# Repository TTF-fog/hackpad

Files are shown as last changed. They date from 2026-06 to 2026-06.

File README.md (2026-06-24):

# hackpad!!
a simple 9-key macropad with backlighting

# Why
- ...i've never made one before
- i did actually need a macropad
- i wanted to use a ribbon connector but didn't have anything that needed one
- i needed to remember how to CAD

# Sub(Links)
- [Zine.pdf](zine.pdf)
- [Design](design/)
- [BOM](BOM.csv)
- [Gerbers](gerbers.zip) 
- [Schematic PDF](design/hackpad.pdf)

> DO FLASHING BEFORE ASSEMBLY!
# flashing
- make sure you have QMK installed
- copy the firmware/firmware directory into the keyboards directory of your qmk installation
- run qmk compile -kb wackpad -km default
- on the xiao, ground the BOOT pad while plugging it into the computer
- drop the resultant .uf2 from the previous previous (englishj) step into the flash drive
- after the copying is done (may take a while), the drive will automatically eject
# hardware assembly
- solder the components
- print the case
- place the pcb in the case so the mounting holes go through the stands
- align the OLED ribbon to go through the display hole
- assembly done!

# images
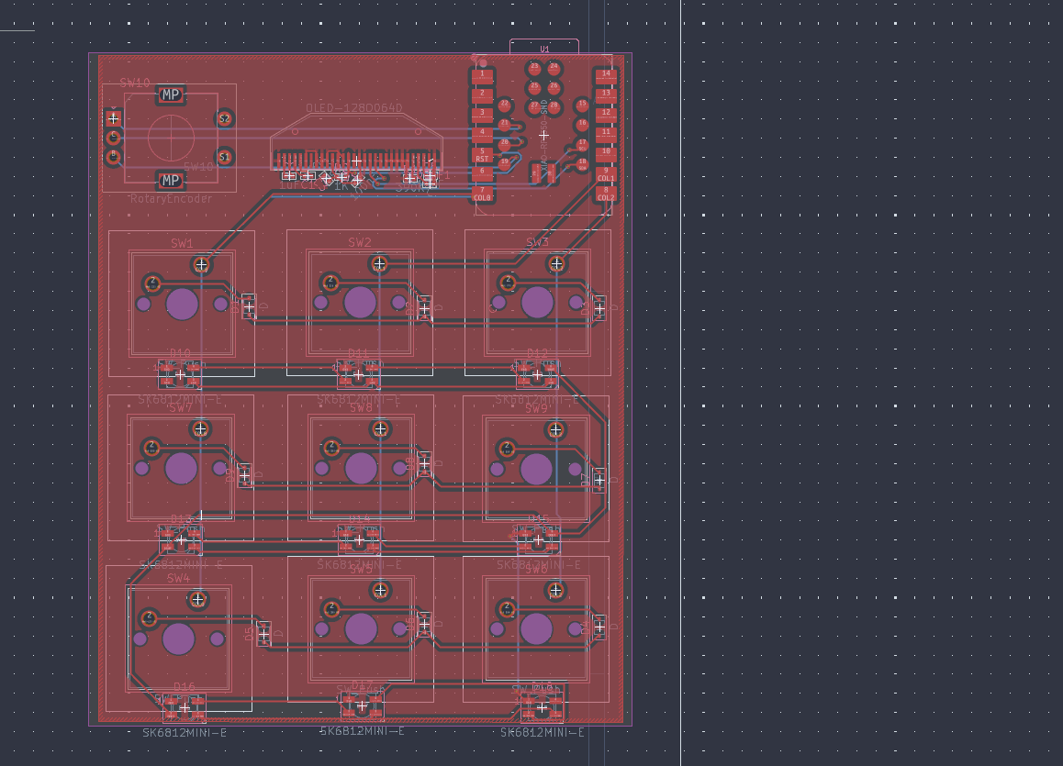
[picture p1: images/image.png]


> PCB

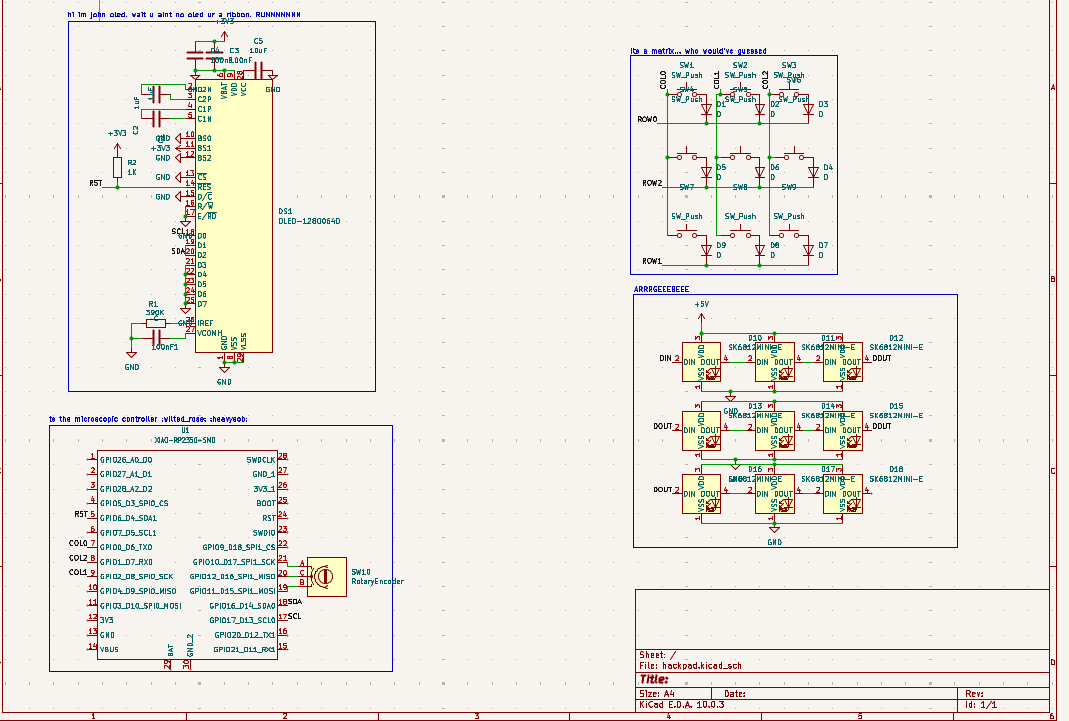
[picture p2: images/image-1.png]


>Schematic

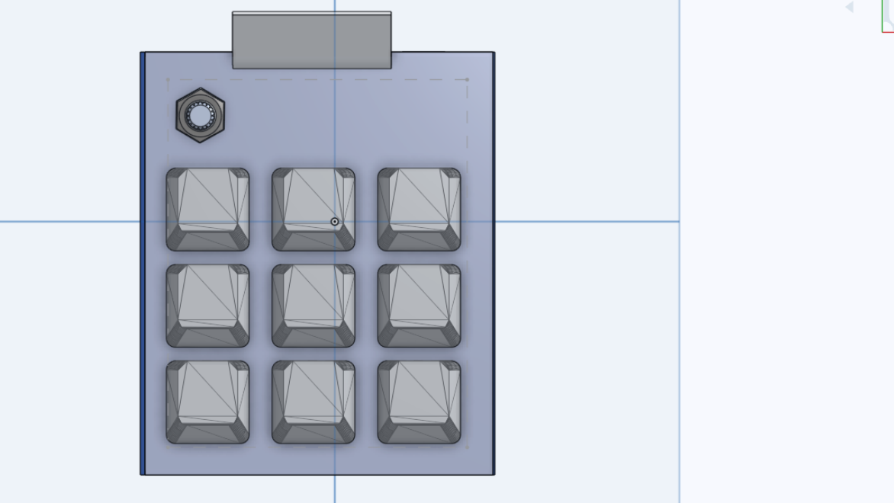
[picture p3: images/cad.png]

> the CAD

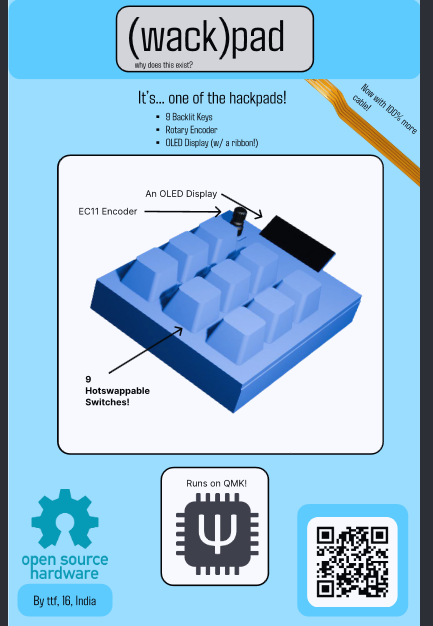
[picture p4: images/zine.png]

> zine img

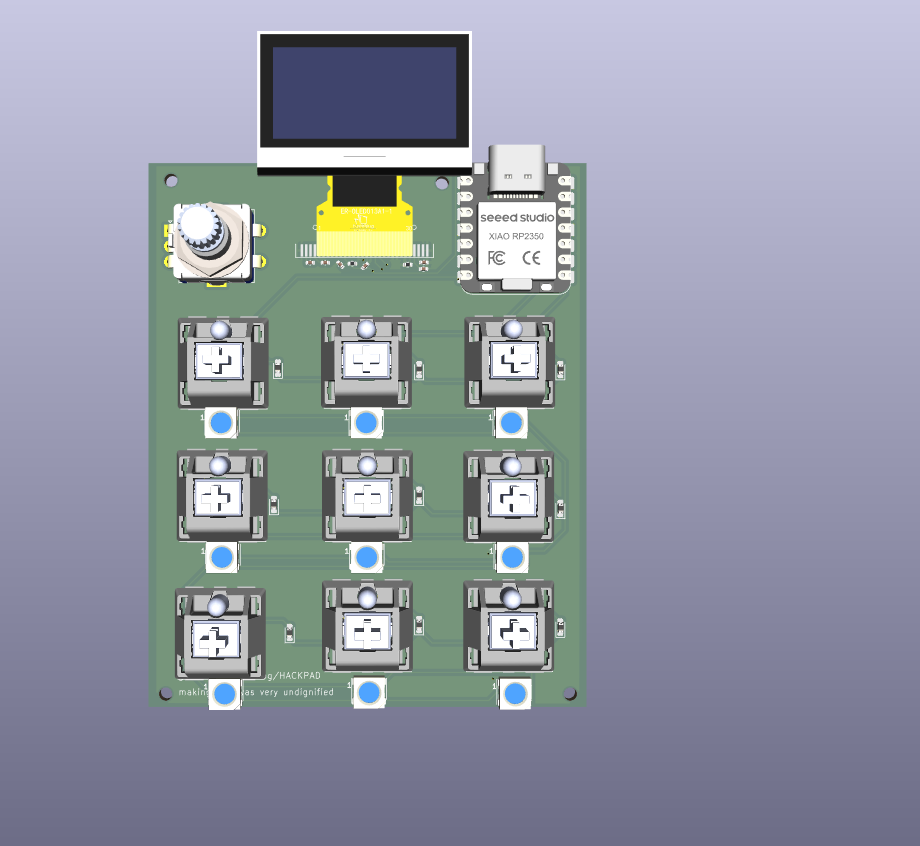
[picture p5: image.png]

>pcb 3dview

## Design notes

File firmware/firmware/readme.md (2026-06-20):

# wackpad

wackpad

*A short description of the keyboard/project*

* Keyboard Maintainer: [TTF-fog](https://github.com/TTF-fog)
* Hardware Supported: *The PCBs, controllers supported*
* Hardware Availability: *Links to where you can find this hardware*

Make example for this keyboard (after setting up your build environment):

    make wackpad:default

Flashing example for this keyboard:

    make wackpad:default:flash

See the [build environment setup](https://docs.qmk.fm/#/getting_started_build_tools) and the [make instructions](https://docs.qmk.fm/#/getting_started_make_guide) for more information. Brand new to QMK? Start with our [Complete Newbs Guide](https://docs.qmk.fm/#/newbs).

## Bootloader

Enter the bootloader in 3 ways:

* **Bootmagic reset**: Hold down the key at (0,0) in the matrix (usually the top left key or Escape) and plug in the keyboard
* **Physical reset button**: Briefly press the button on the back of the PCB - some may have pads you must short instead
* **Keycode in layout**: Press the key mapped to `QK_BOOT` if it is available

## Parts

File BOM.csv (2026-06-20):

Comment | Designator | Footprint | LCSC | Quantity | Link | Price/Unit | Price (Total)
100nF | C3,C4 | C_0402_1005Metric | C1525 | 2 | https://lcsc.com/product-detail/C1525.html | 0.0031 | 0.31
10uF | C5 | C_0402_1005Metric | C15525 | 1 | https://lcsc.com/product-detail/C15525.html | 0.0199 | 1.99
1K | R2 | R_0402_1005Metric | C11702 | 1 | https://lcsc.com/product-detail/C11702.html | 0.0011 | 0.11
1uF | C1,C2 | C_0402_1005Metric | C52923 | 2 | https://lcsc.com/product-detail/C52923.html | 0.0143 | 0.72
390K | R1 | R_0402_1005Metric | C25557 | 1 | https://lcsc.com/product-detail/C25557.html | 0.0007 | 0.07
C | 100nF1 | C_0402_1005Metric | C1525 | 1 | https://lcsc.com/product-detail/C1525.html | 0.0031 | 0.31
D | D1,D2,D3,D4,D5,D6,D7,D8,D9 | D_SOD-323 | N/A | 9 | https://robu.in/product/1n4148ws-7-f-diodes-incorporated-75v-independent-1-25v150ma-4ns-150ma-sod-323-switching-diodes-rohs/ | 0.05 | 0.45
SK6812MINI-E | D10,D11,D12,D13,D14,D15,D16,D17,D18 | LED_SK6812MINI_PLCC4_3.5x3.5mm_P1.75mm | C5149201 | 9 | https://lcsc.com/product-detail/C5149201.html | 0.0876 | 0.7884
SW_Push | SW1,SW2,SW3,SW4,SW5,SW6,SW7,SW8,SW9 | SW_Cherry_MX_1.00u_PCB | N/A | 9 | https://meckeys.com/shop/accessories/keyboard-accessories/key-switches/cherry-mx2a-switch/ | 0.46 | 4.6
RotaryEncoder | SW10 | RotaryEncoder_Alps_EC11E-Switch_Vertical_H20mm | N/A | 1 | https://robu.in/product/hongyan-ec11h-7ce20p1zy20-rotary-encoder-with-push-button-switch-vertical-plug-in-5-pin/ | 0.58 | 0.58
XIAO-RP2350-SMD | U1 | XIAO-RP2350-SMD | N/A | 1 | https://robu.in/product/seeedstudio-xiao-rp2350-raspberry-pi-rp2350/ | 8.4 | 8.4
OLED-128O064D | DS1 | OLED-128O064D | N/A | 1 | https://robu.in/product/oled-with-ssd1306/ | 1.6 | 1.6
PCB Milling | N/A | N/A | N/A | 1 | https://jlcpcb.com | 2 | 2
 |  |  |  |  |  | 13.2167 | 21.9284

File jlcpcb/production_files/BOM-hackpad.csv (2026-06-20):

Comment | Designator | Footprint | LCSC | Quantity
100nF | C3,C4 | C_0402_1005Metric | C1525 | 2
10uF | C5 | C_0402_1005Metric | C15525 | 1
1K | R2 | R_0402_1005Metric | C11702 | 1
1uF | C1,C2 | C_0402_1005Metric | C52923 | 2
390K | R1 | R_0402_1005Metric | C25557 | 1
C | 100nF1 | C_0402_1005Metric | C1525 | 1
D | D1,D2,D3,D4,D5,D6,D7,D8,D9 | D_SOD-323 | C1046 | 9
SK6812MINI-E | D10,D11,D12,D13,D14,D15,D16,D17,D18 | LED_SK6812MINI_PLCC4_3.5x3.5mm_P1.75mm | C5149201 | 9
SW_Push | SW1,SW2,SW3,SW4,SW5,SW6,SW7,SW8,SW9 | SW_Cherry_MX_1.00u_PCB | C6482 | 9
RotaryEncoder | SW10 | RotaryEncoder_Alps_EC11E-Switch_Vertical_H20mm |  | 1
XIAO-RP2350-SMD | U1 | XIAO-RP2350-SMD |  | 1
OLED-128O064D | DS1 | OLED-128O064D |  | 1

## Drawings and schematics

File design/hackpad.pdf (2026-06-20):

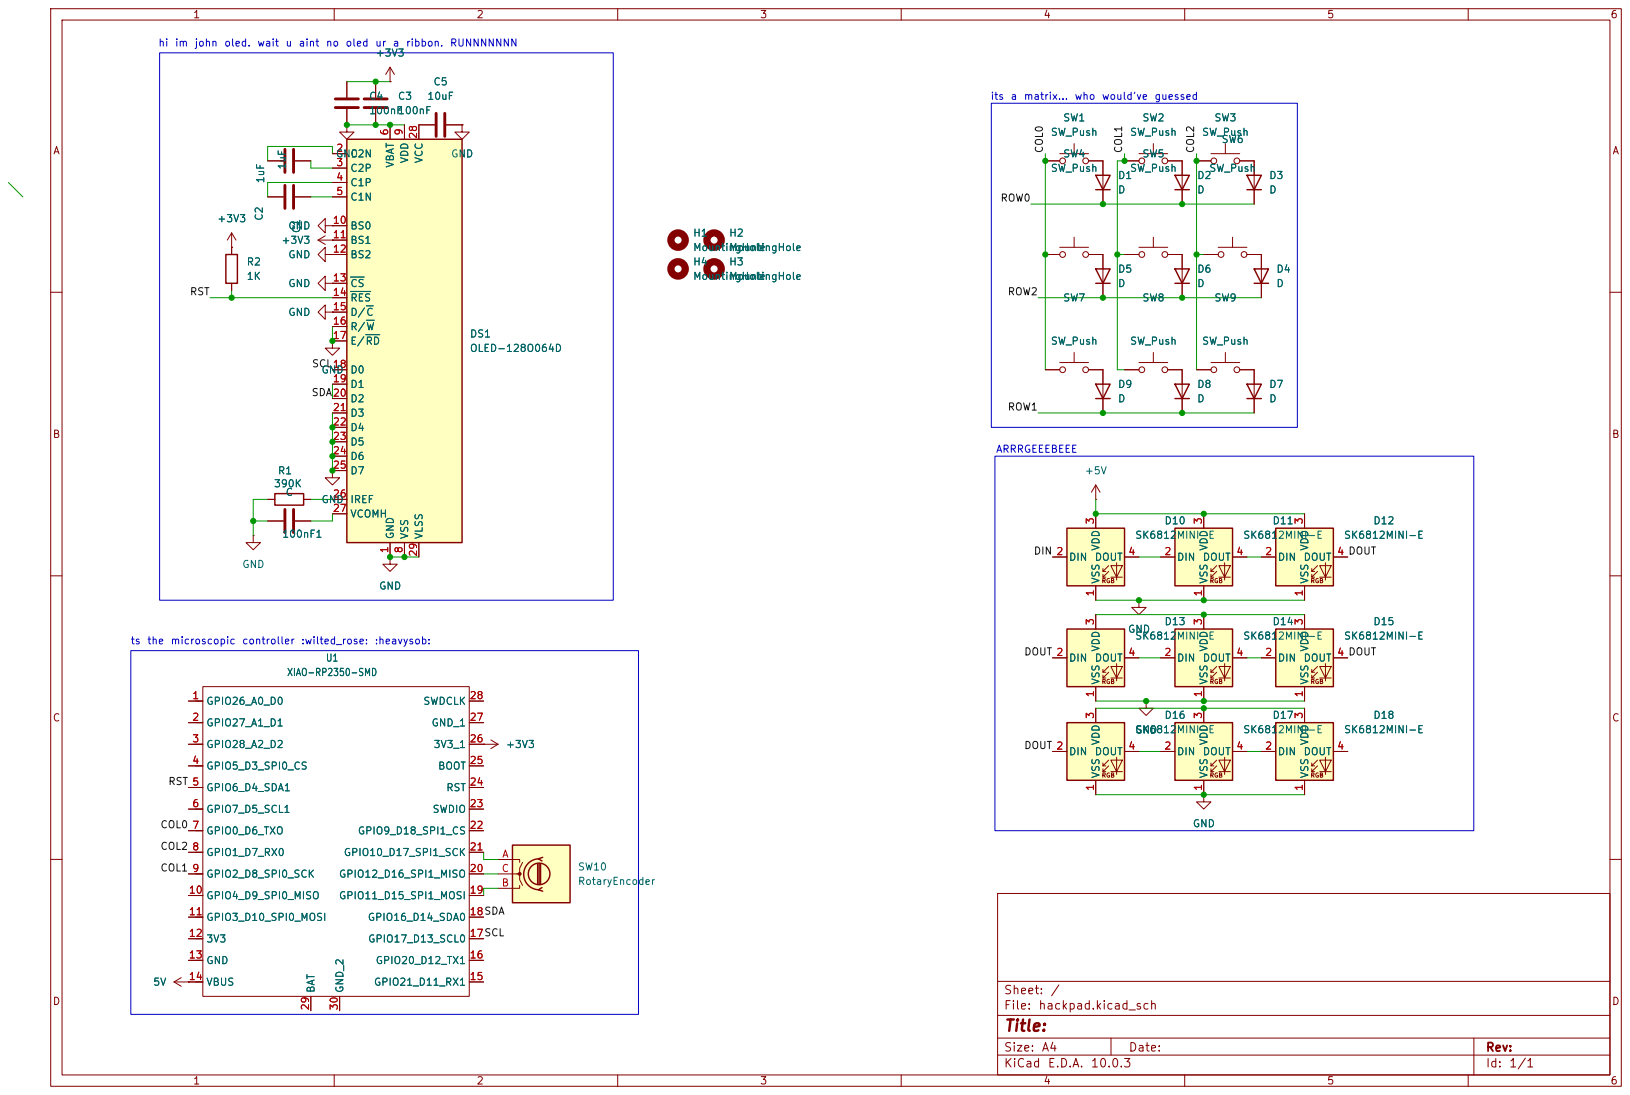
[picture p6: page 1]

hi im john oled. wait u aint no oled ur a ribbon. RUNNNNNNN

its a matrix... who would've guessed

ts the microscopic controller :wilted_rose: :heavysob:

Size: A4 | Rev:
KiCad E.D.A. 10.0.3 | Id: 1/1

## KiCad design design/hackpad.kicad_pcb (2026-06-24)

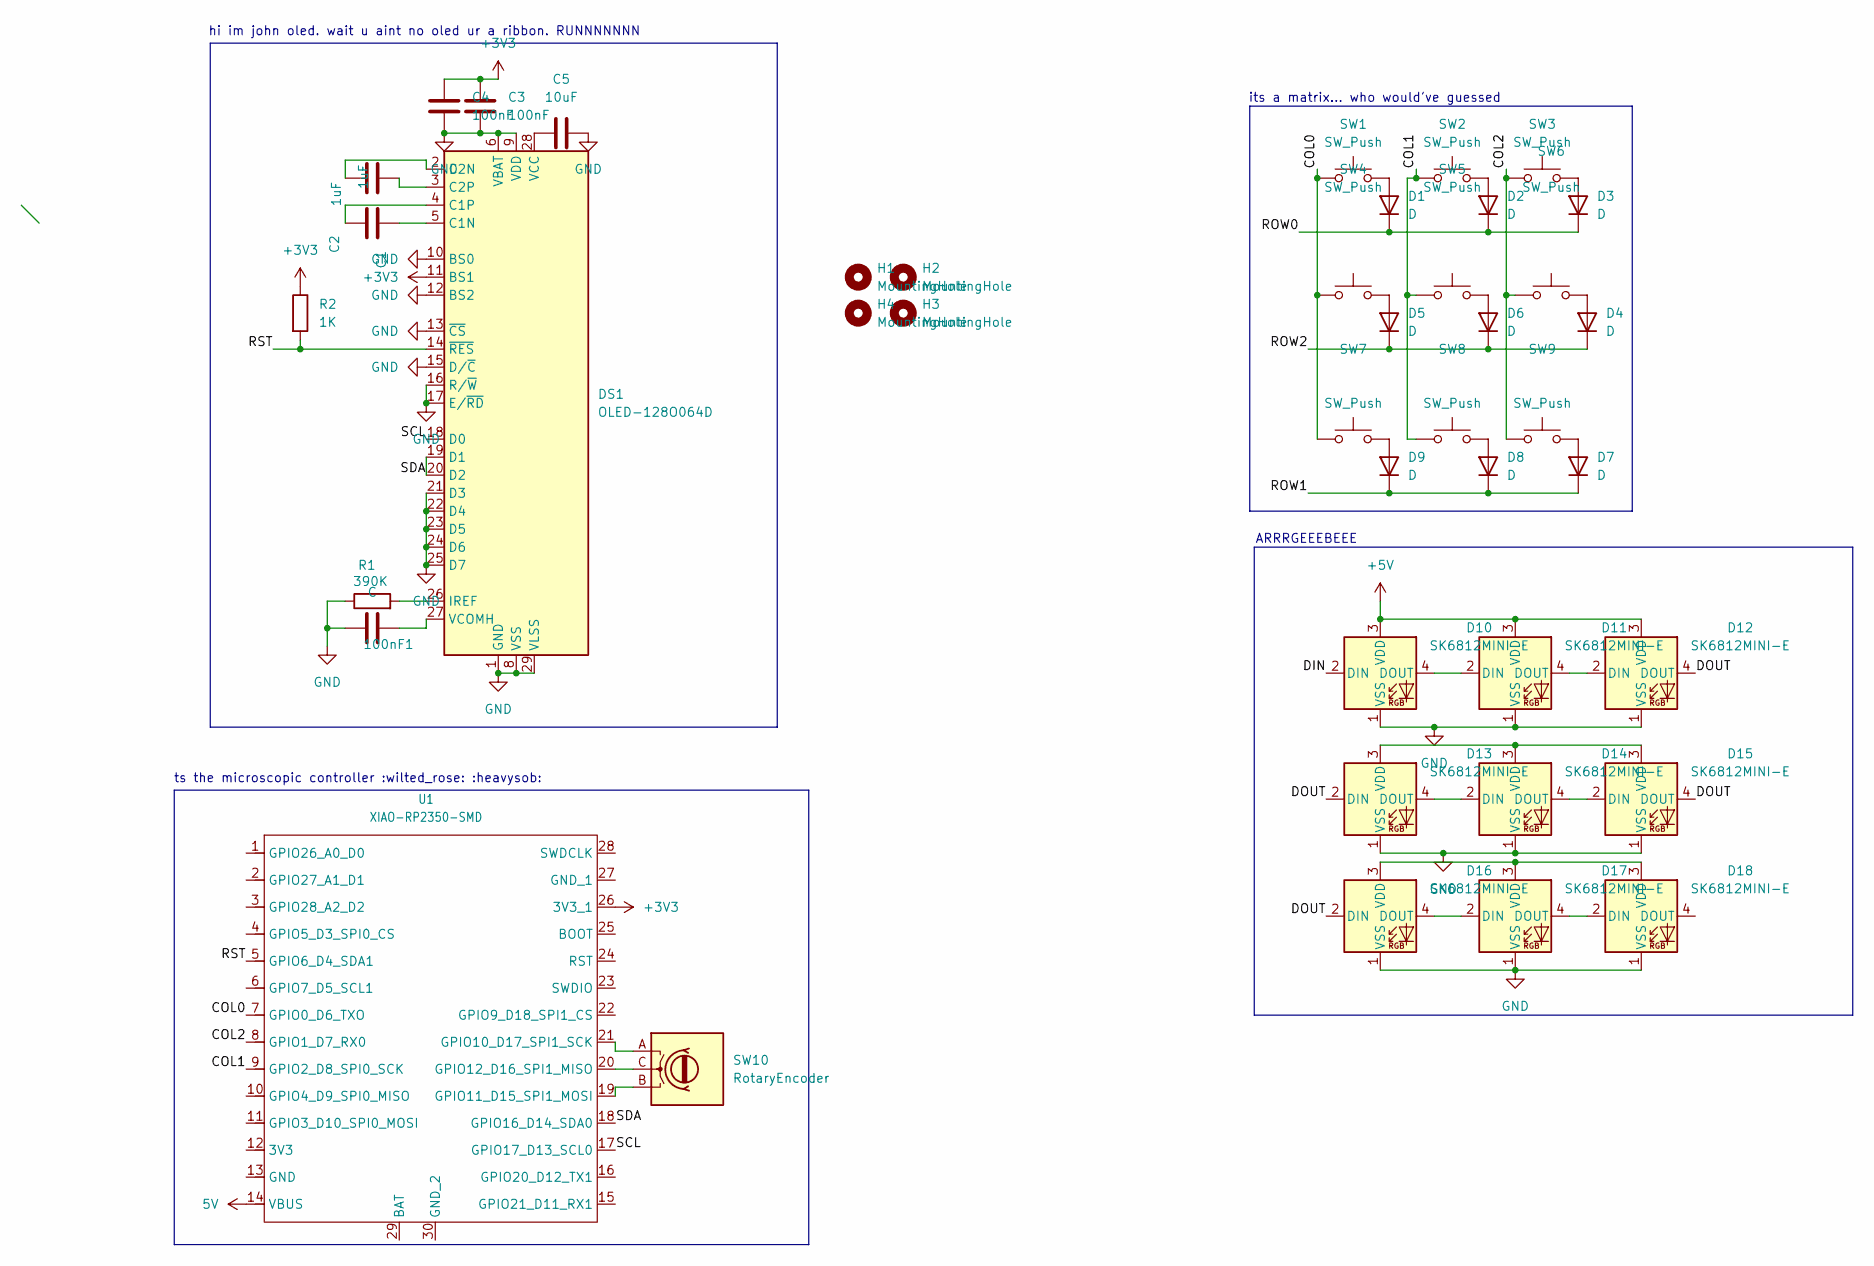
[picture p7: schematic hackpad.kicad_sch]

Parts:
100nF1: C; C_0402_1005Metric
C1, C2: 1uF; C_0402_1005Metric
C3, C4: 100nF; C_0402_1005Metric
C5: 10uF; C_0402_1005Metric
D1, D2, D3, D4, D5, D6, D7, D8, D9: D; D_0603_1608Metric_Pad1.05x0.95mm_HandSolder
D10, D11, D12, D13, D14, D15, D16, D17, D18: SK6812MINI-E; LED_SK6812MINI_PLCC4_3.5x3.5mm_P1.75mm
DS1: OLED-128O064D
H1, H2, H3, H4: MountingHole; MountingHole_2.1mm
R1: 390K; R_0402_1005Metric
R2: 1K; R_0402_1005Metric
SW1, SW2, SW3, SW4, SW5, SW6, SW7, SW8, SW9: SW_Push; SW_Cherry_MX_1.00u_PCB
SW10: RotaryEncoder; RotaryEncoder_Alps_EC11E-Switch_Vertical_H20mm
U1: XIAO-RP2350-SMD

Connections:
5V: U1.14 (VBUS)
+3V3: C3.1, C4.1, DS1.11 (BS1), R2.1, U1.26 (3V3_1)
+5V: D10.3 (VDD), D11.3 (VDD), D12.3 (VDD)
/COL0: SW1.1, SW4.1, SW7.1, U1.7 (GPIO0_D6_TXO)
/COL1: SW2.1, SW5.1, SW8.1, U1.9 (GPIO2_D8_SPI0_SCK)
/COL2: SW3.1, SW6.1, SW9.1, U1.8 (GPIO1_D7_RX0)
/DIN: D10.2 (DIN)
/DOUT: D12.4 (DOUT), D13.2 (DIN), D15.4 (DOUT), D16.2 (DIN)
/ROW0: D1.1 (K), D2.1 (K), D3.1 (K)
/ROW1: D7.1 (K), D8.1 (K), D9.1 (K)
/ROW2: D4.1 (K), D5.1 (K), D6.1 (K)
/RST: DS1.14 (~RES), R2.2, U1.5 (GPIO6_D4_SDA1)
/SCL: DS1.18 (D0), U1.17 (GPIO17_D13_SCL0)
/SDA: DS1.19 (D1), DS1.20 (D2), U1.18 (GPIO16_D14_SDA0)
GND: 100nF1.2, C3.2, C4.2, C5.2, D10.1 (VSS), D11.1 (VSS), D12.1 (VSS), D13.1 (VSS), D14.1 (VSS), D15.1 (VSS), D16.1 (VSS), D17.1 (VSS), D18.1 (VSS), DS1.1 (GND), DS1.6 (VBAT), DS1.8 (VSS), DS1.9 (VDD), DS1.10 (BS0), DS1.12 (BS2), DS1.13 (~CS), DS1.15 (D/~C), DS1.16 (R/~W), DS1.17 (E/~RD), DS1.21 (D3), DS1.22 (D4), DS1.23 (D5), DS1.24 (D6), DS1.25 (D7), DS1.29 (VLSS), DS1.30 (GND), R1.1
unnamed: D1.2 (A), SW1.2
unnamed: D2.2 (A), SW2.2
unnamed: D3.2 (A), SW3.2
unnamed: D4.2 (A), SW6.2
unnamed: D5.2 (A), SW4.2
unnamed: D6.2 (A), SW5.2
unnamed: D7.2 (A), SW9.2
unnamed: D8.2 (A), SW8.2
unnamed: D9.2 (A), SW7.2
unnamed: D10.4 (DOUT), D11.2 (DIN)
unnamed: D11.4 (DOUT), D12.2 (DIN)
unnamed: D13.4 (DOUT), D14.2 (DIN)
unnamed: D13.3 (VDD), D14.3 (VDD), D15.3 (VDD)
unnamed: D14.4 (DOUT), D15.2 (DIN)
unnamed: D16.4 (DOUT), D17.2 (DIN)
unnamed: D16.3 (VDD), D17.3 (VDD), D18.3 (VDD)
unnamed: D17.4 (DOUT), D18.2 (DIN)
unnamed: C1.1, DS1.5 (C1N)
unnamed: C1.2, DS1.4 (C1P)
unnamed: C2.1, DS1.2 (C2N)
unnamed: C2.2, DS1.3 (C2P)
unnamed: DS1.26 (IREF), R1.2
unnamed: C5.1, DS1.28 (VCC)
unnamed: 100nF1.1, DS1.27 (VCOMH)
unnamed: SW10.A, U1.21 (GPIO10_D17_SPI1_SCK)
unnamed: SW10.B, U1.19 (GPIO11_D15_SPI1_MOSI)
unnamed: SW10.C, U1.20 (GPIO12_D16_SPI1_MISO)

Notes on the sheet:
hi im john oled. wait u aint no oled ur a ribbon. RUNNNNNNN
its a matrix... who would've guessed
ts the microscopic controller :wilted_rose: :heavysob:
ARRRGEEEBEEE

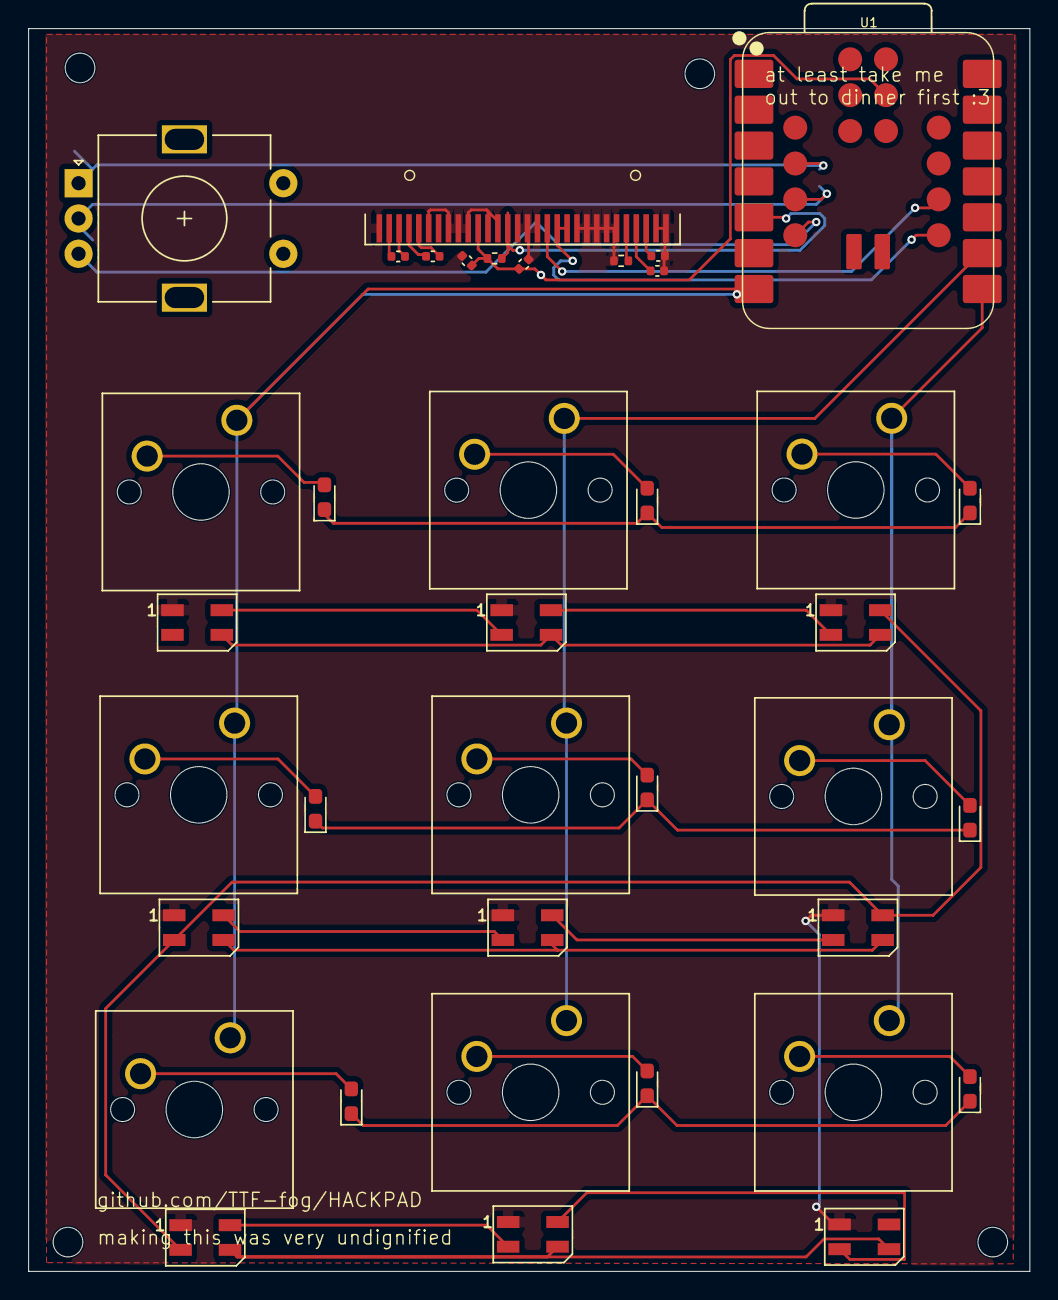
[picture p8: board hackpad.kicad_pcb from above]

Board: 2 copper layers, 70.9 x 88.0 mm, 42 parts (0 on the bottom side), 40 nets.

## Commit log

2026-06-20 ADD FIRST
    [hackpad.kicad_pcb, hackpad.kicad_sch]
2026-06-20 remove ss trext
    [hackpad.kicad_pcb]
2026-06-20 add firmware, forgor to add the 5v net
    [hackpad.kicad_pcb, hackpad.kicad_sch]
2026-06-20 updatre hackpad, add assemblie(s)
    [hackpad.kicad_pcb]
2026-06-20 add more silkscreen tezt
    [hackpad.kicad_pcb]
2026-06-24 add cad pictre
